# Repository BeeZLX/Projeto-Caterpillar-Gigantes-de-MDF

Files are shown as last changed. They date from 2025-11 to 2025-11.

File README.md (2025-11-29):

Programação de HardWare 2025

Grupo Caterpillar:

Vinicius Regis
Leticia Ribeiro
Caio Rodrigues

O projeto Gigantes de MDF envolve a criação integral de um robô móvel construído em MDF, incluindo todo o sistema de locomoção formado por motores DC acionados por PWM, um mecanismo de disparo a laser utilizando um diodo emissor de luz vermelho e um módulo de detecção baseado em LDR acoplado a um difusor.

A proposta do trabalho é colocar em prática os conteúdos estudados na disciplina de Programação de Hardware, operando diretamente com o microcontrolador ATmega328p, buscando apenas pelos componentes essenciais para o funcionamento básico do sistema.

Regras do Edital:
Dimensões máximas de 200 × 200 × 200 mm • Sistema com 2 a 4 rodas, capaz de realizar movimentação no próprio eixo • “Arma” laser posicionada no centro do robô, a 100 mm de altura • Receptor de luz instalado ao lado direito da arma, com difusor de 20 mm • Estrutura baseada em MDF, com cortes e montagem conforme projeto disponibilizado

O gigante de MDF deve cumprir as seguintes especificações:
 Utilizar o Microcontrolador ATmega328P, ter Controle dos motores via PWM, Laser temporizado por Timer, Receptor de luz (LDR) com rotina de interrupção, após cada acerto é obrigatorio ter um delay, utilização de leds para a simulação da "vida" do robõ, Rotina de giro automático de 180°, Reset de vidas via interrupção externa e ter o Código completamente documentado em Doxygen

Todo o conjunto — circuito eletrônico, firmware e documentação — foi idealizado, desenvolvido e implementado pela equipe.

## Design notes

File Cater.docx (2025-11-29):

Catepillar

Vinicius de Moraes Regis - RA: 230610

Leticia Ribeiro - RA: 233423

Caio Rodrigues - RA: 228282

# 1.Introdução do Projeto

O projeto gigantes de MDF desenvolvido para a matéria de Programação de Hardware, consiste em um robô que compõe de componentes eletrônicos como laser, Motor Dc e um LDR como sistema de recepção de luz.

Operando com o microcontrolado ATMEGA328P, temos o objetivo de aplicar os conhecimentos adquiridos nas aulas como TIMERS, PWM, UART, CTC e outros.

Sendo todas as etapas testadas e por fim, realizadas pelos integrantes do grupo, sendo elas circuito, estrutura, Software e documentação.

2. Composição da estrutura do Projeto

O robô realizado pelos alunos atendem as medidas (Dimensões) maximas de: 160 x 168.5 x 160mm, inteiramente feito de MDF (3mm) com ajuda do laboratório INOVFABLAB da UNIVERSIDADE SANTA CECÍLIA, contém com um sistema de movimentação de 2 (duas rodas) ligadas à 2 (dois) motores DC 3-6V,

1 (um) Circuito integrado de motor L293D, 1 (um) componente eletrônico (sensor de luz) LDR (20mm), 1 (um) laser vermelho de 300mW de Potência, 6 (seis) leds, sendo eles 3 para a vida do “GIGANTE DE MDF” e mais 3 como componente estético, 1 (um) Módulo Bluetooth HC-05 para a comunicação entre o robô, 2 (dois) Servo Motor como arma e o usuário e 2 (dois) microcontroladores ATMEGA328P.

Robô realizado atraves do Software: Fusion 360

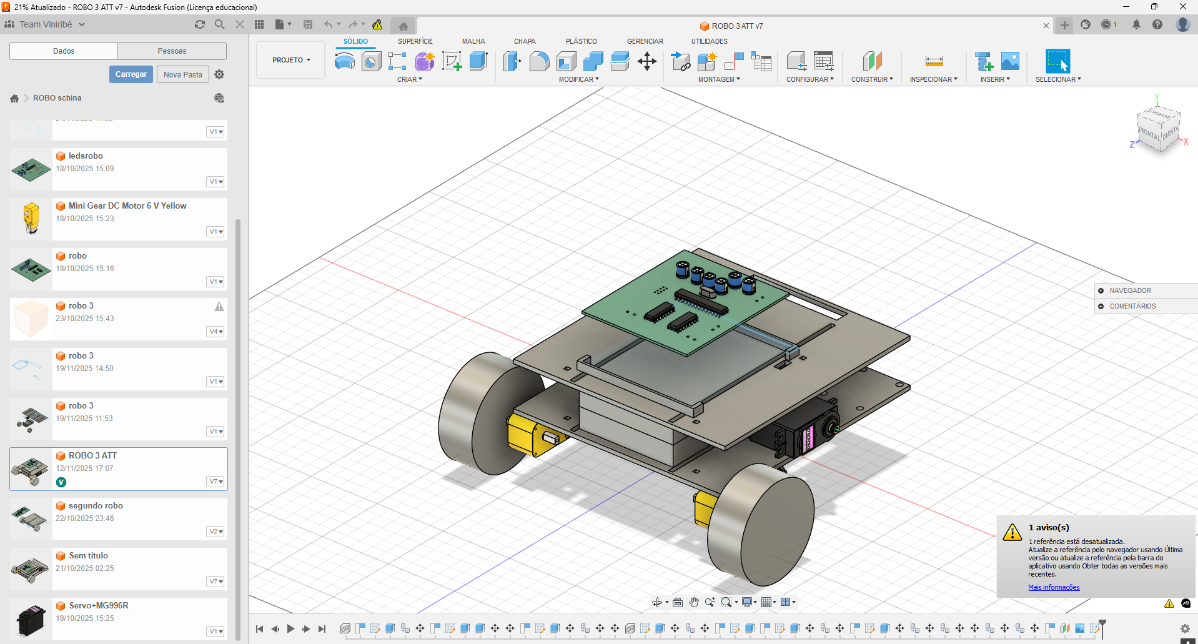
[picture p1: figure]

Circuitos realizados através do Software: KICAD

Circuito principal “Coração” do Gigante de MDF

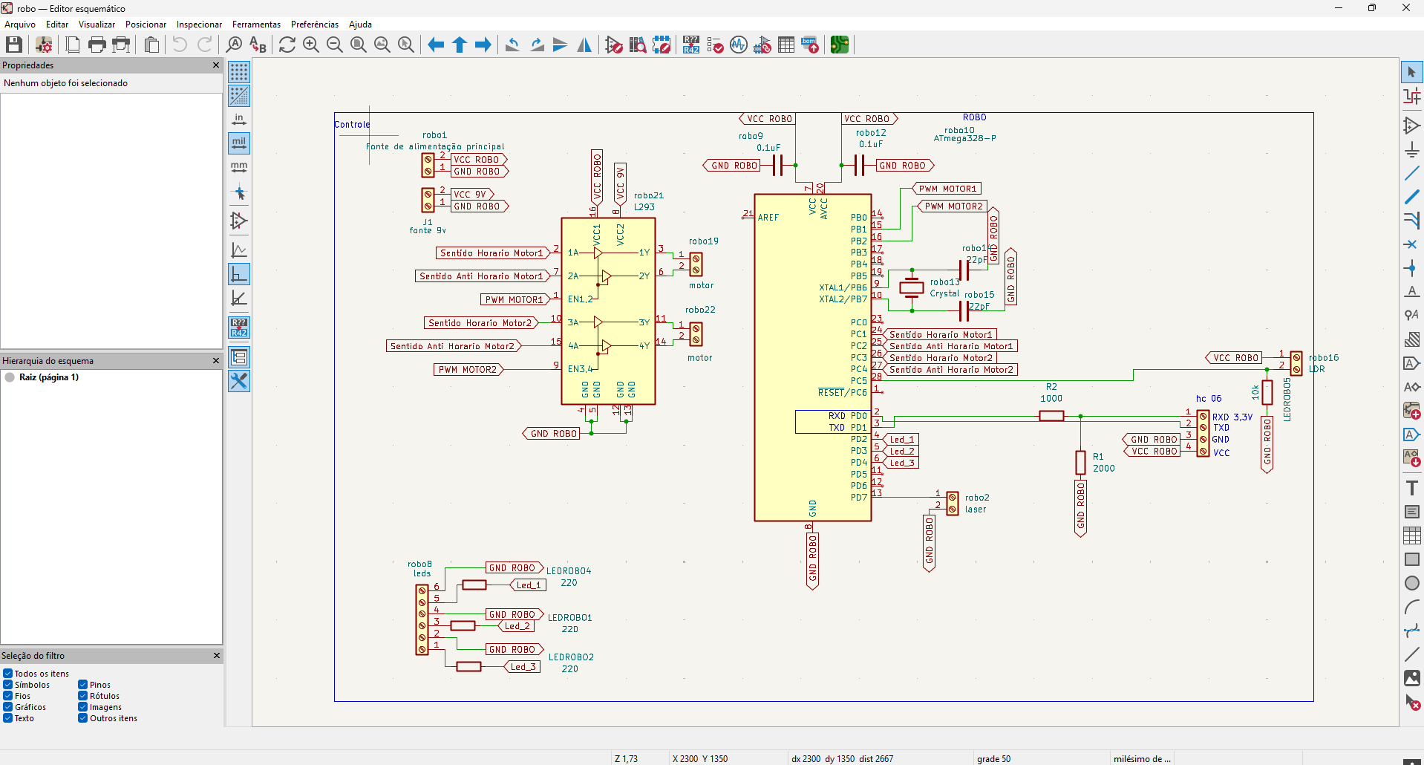
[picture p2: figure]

Circuito para as armas (Servos Motores)

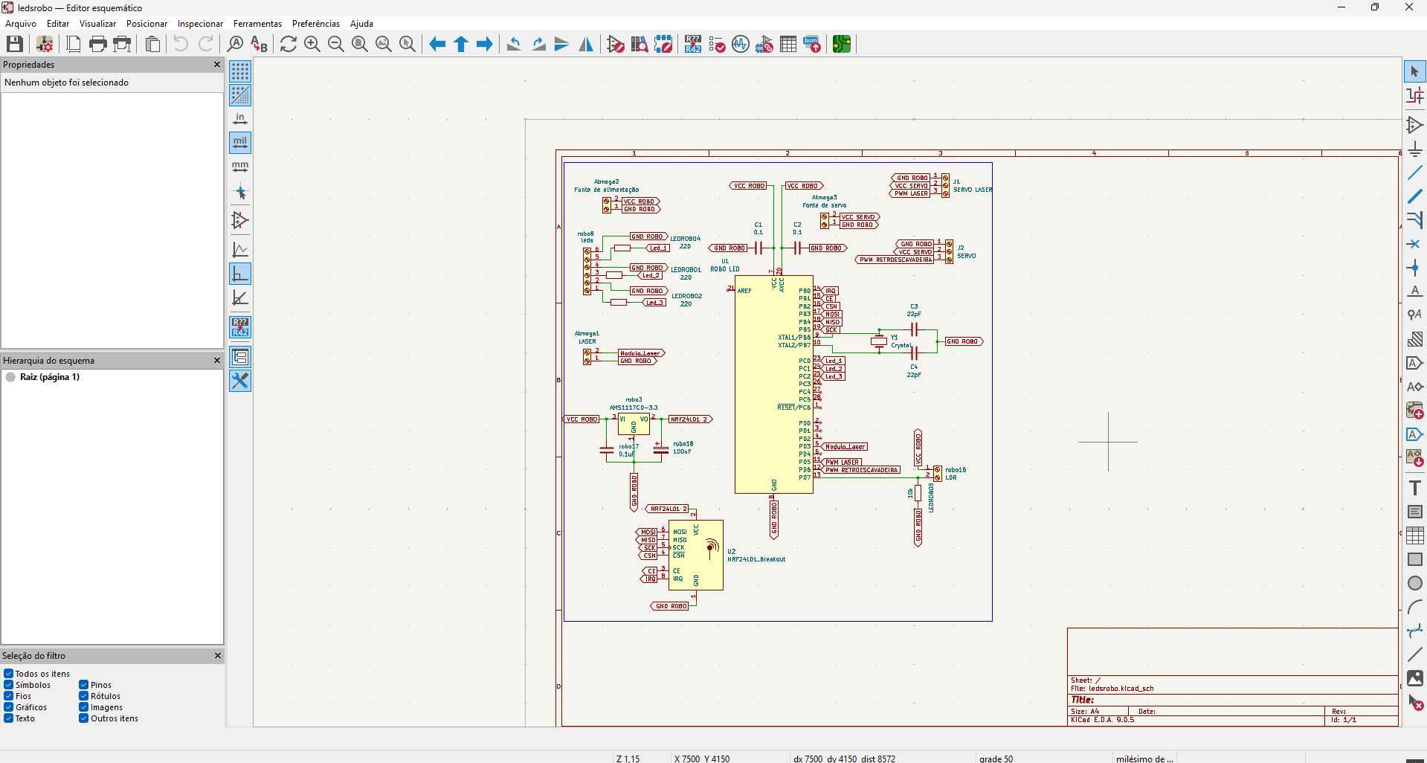
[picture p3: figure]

# 4.Simulação e Firmware

Antes da confecção das placas de Circuito, os alunos realizaram testes no simulados “Simulide”, fazendo com que toda a lógica por trás da construção do robô pudesse ser validada, reduzindo os riscos de falha e aumentando o sucesso do objetivo.

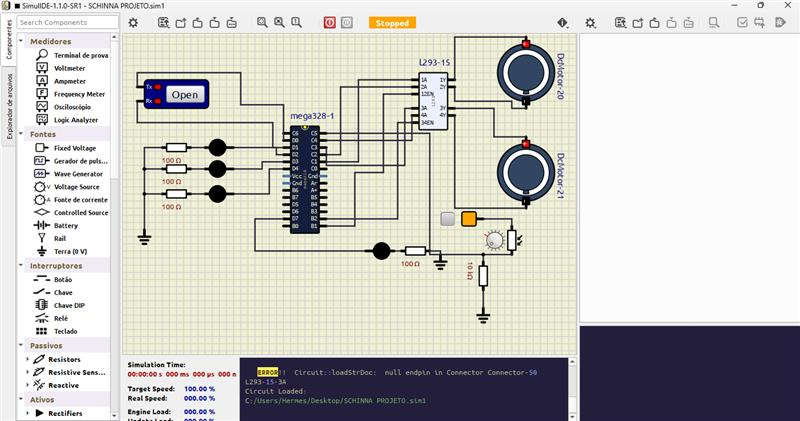
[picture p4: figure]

Após a criação e montagem da placa de circuito, os alunos realizaram a parte de firmware na linguagem C, utilizando todos os ensinamentos dado em aula em relação à TIMERS e PWM das aulas de Programações de Hardware

Para o desenvolvimento do projeto, foi utilizado os seguintes aplicativos:

Simulide: Aplicativo para a simulação de circuitos eletrônicos .

Fusion 360: Aplicativo utilizado para a medição e criação das estruturas do robô.

KICAD: Aplicativo para a criação das placas de circuitos.

Microchip Studio: Ambiente de programação para realizar os testes no simulide.

Arduino IDE: plataforma Arduino utilizado para a transferência de dados do programador para o microcontrolador ATMEGA328P.

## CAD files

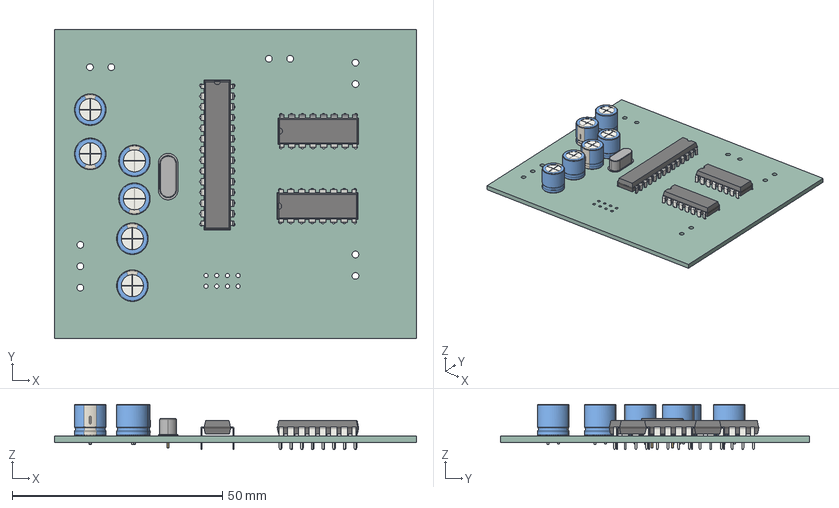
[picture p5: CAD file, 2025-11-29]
robo.step
86.0 x 73.5 x 10.8 mm
DIP-16_W7.62mm x 2
CP_Radial_D7.5mm_P2.50mm x 6
DIP-28_W7.62mm
Crystal_HC49-4H_Vertical
robo_PCB

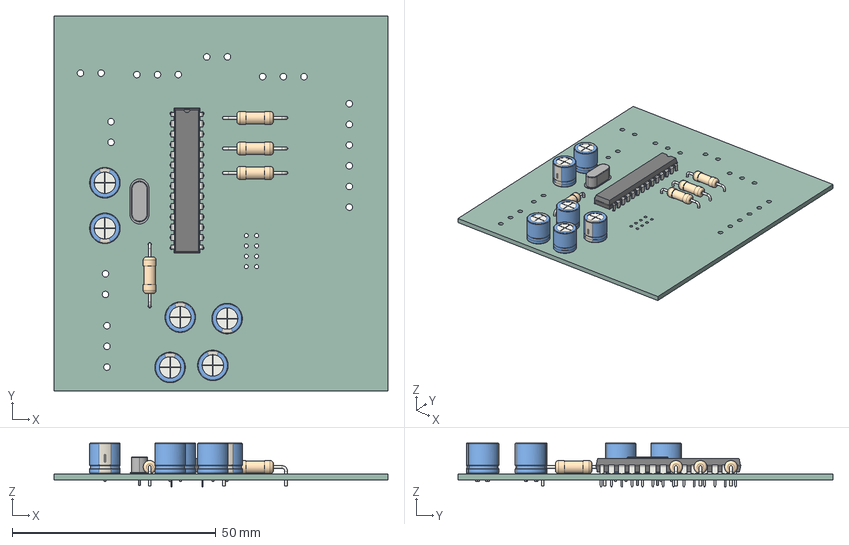
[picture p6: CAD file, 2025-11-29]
ledsrobo.step
82.0 x 92.0 x 10.8 mm
CP_Radial_D7.5mm_P2.50mm x 6
R_Axial_DIN0309_L9.0mm_D3.2mm_P15.24mm_Horizontal x 4
DIP-28_W7.62mm
Crystal_HC49-4H_Vertical
ledsrobo_PCB

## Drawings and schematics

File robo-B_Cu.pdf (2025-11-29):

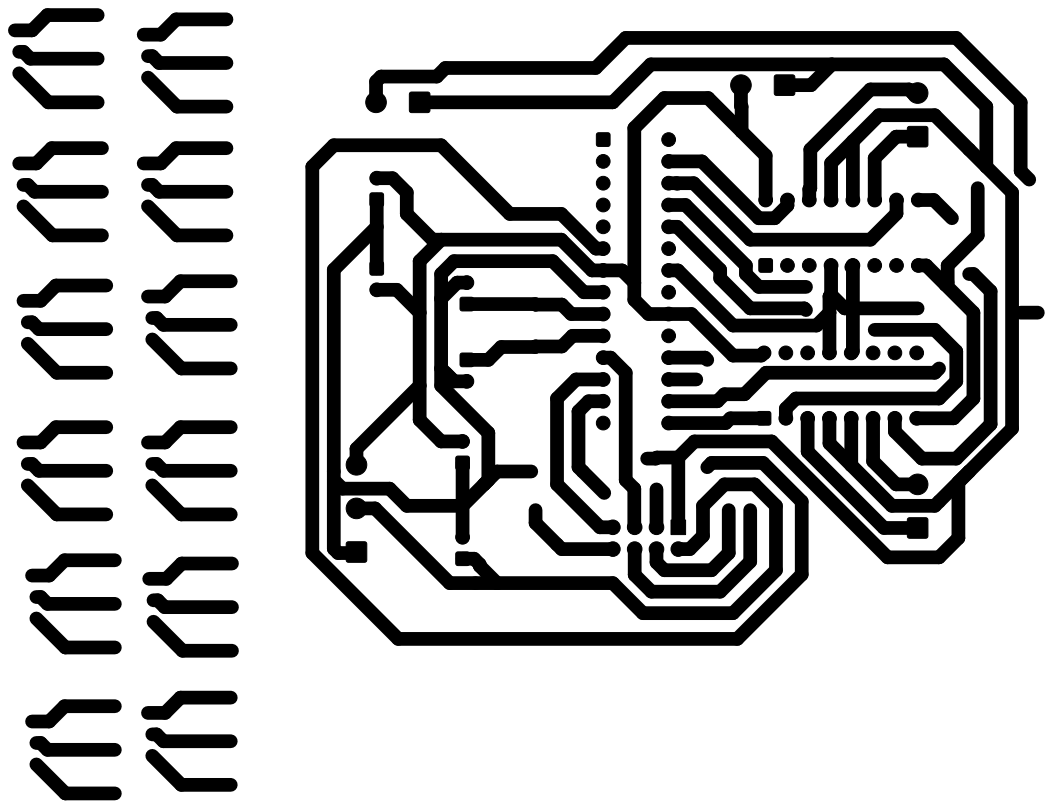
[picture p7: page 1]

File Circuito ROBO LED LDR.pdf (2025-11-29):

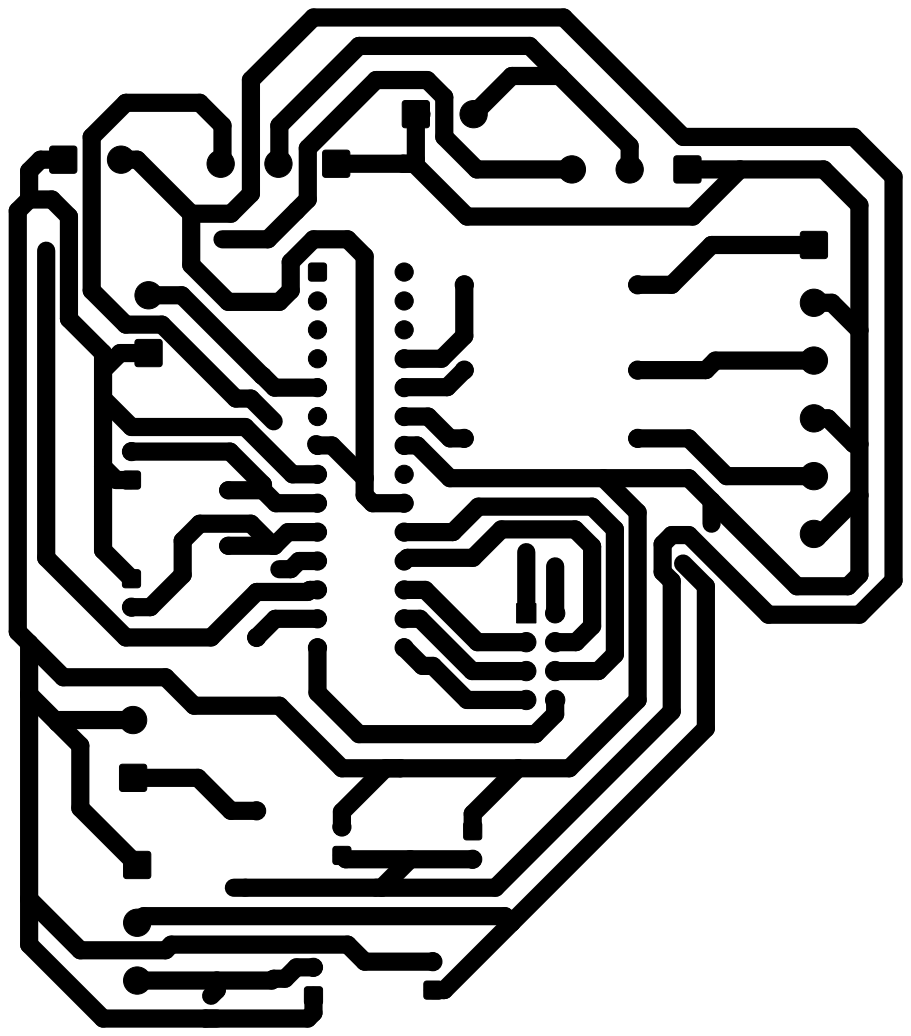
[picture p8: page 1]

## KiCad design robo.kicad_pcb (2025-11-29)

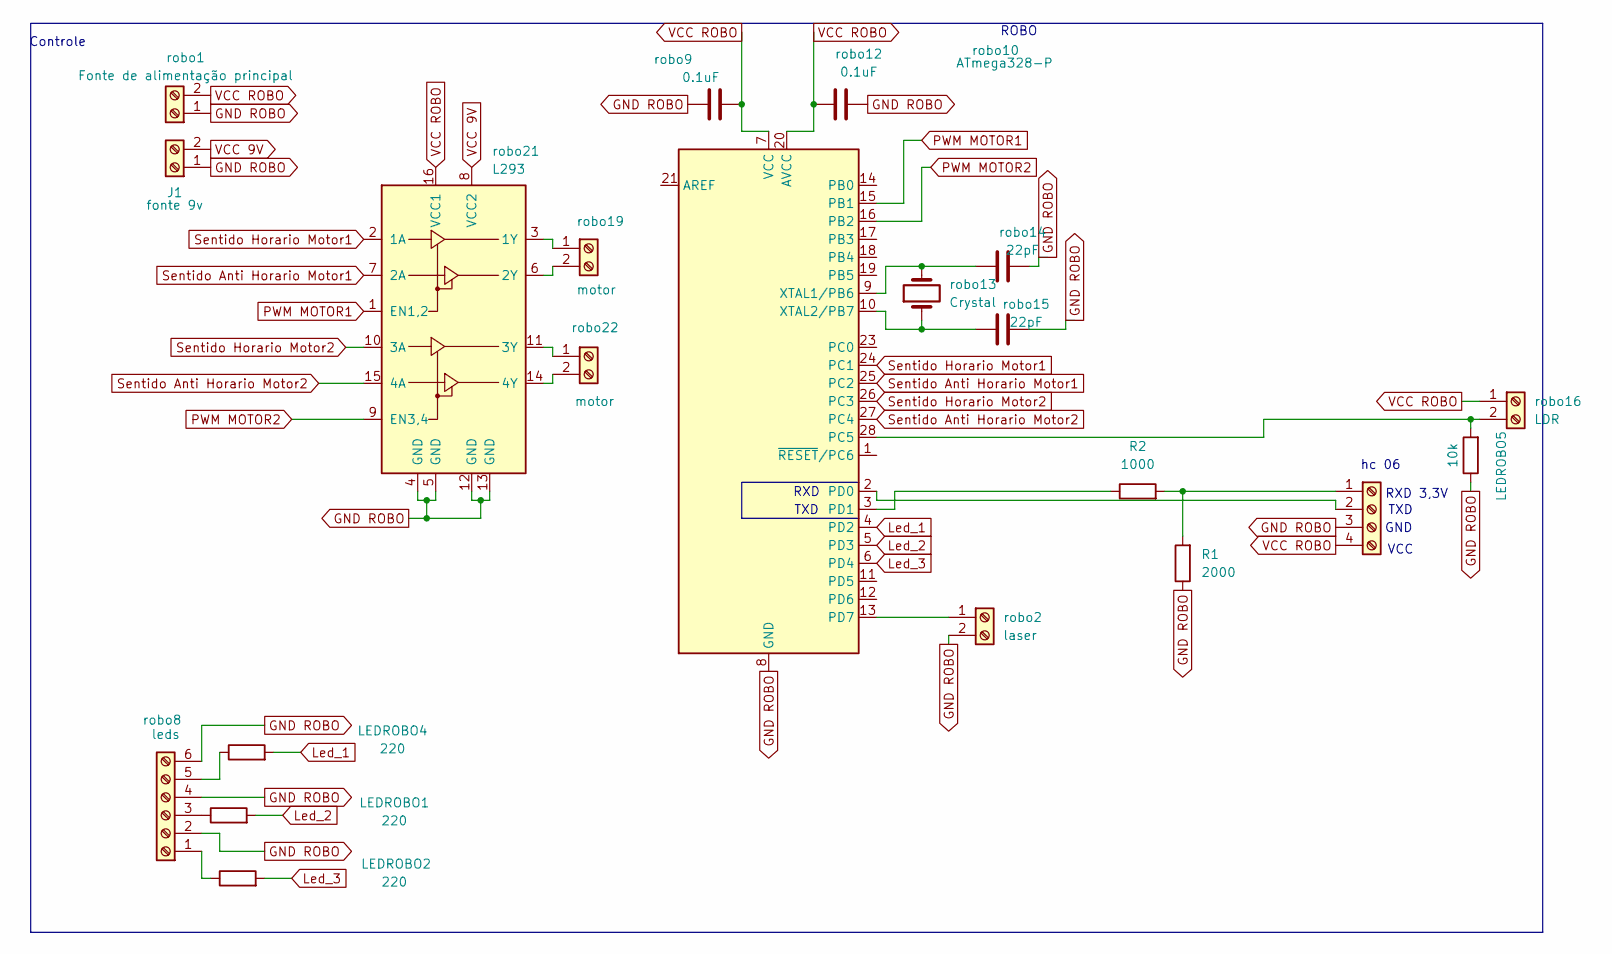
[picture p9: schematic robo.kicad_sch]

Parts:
J1: fonte 9v; TerminalBlock_CUI_TB007-508-02_1x02_P5.08mm_Horizontal
J3: hc06; TerminalBlock_CUI_TB007-508-04_1x04_P5.08mm_Horizontal
LEDROBO1, LEDROBO2, LEDROBO4: 220; R_Axial_DIN0309_L9.0mm_D3.2mm_P15.24mm_Horizontal
LEDROBO5: 10k; R_Axial_DIN0309_L9.0mm_D3.2mm_P15.24mm_Horizontal
R1: 2000; R_Axial_DIN0309_L9.0mm_D3.2mm_P15.24mm_Horizontal
R2: 1000; R_Axial_DIN0309_L9.0mm_D3.2mm_P15.24mm_Horizontal
robo1: Fonte de alimentação principal; TerminalBlock_CUI_TB007-508-02_1x02_P5.08mm_Horizontal
robo2: laser; TerminalBlock_CUI_TB007-508-02_1x02_P5.08mm_Horizontal
robo8: leds; TerminalBlock_CUI_TB007-508-06_1x06_P5.08mm_Horizontal
robo9, robo12: 0.1uF; CP_Radial_D7.5mm_P2.50mm
robo10: ATmega328-P; DIP-28_W7.62mm
robo13: Crystal; Crystal_HC49-4H_Vertical
robo14, robo15: 22pF; CP_Radial_D7.5mm_P2.50mm
robo16: LDR; TerminalBlock_CUI_TB007-508-02_1x02_P5.08mm_Horizontal
robo19, robo22: motor; TerminalBlock_CUI_TB007-508-02_1x02_P5.08mm_Horizontal
robo21: L293; DIP-16_W7.62mm

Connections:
GND ROBO: J1.1, J3.3, LEDROBO5.1, R1.1, robo1.1, robo2.2, robo8.2, robo8.4, robo8.6, robo9.1, robo10.8 (GND), robo10.22 (GND), robo12.1, robo14.2, robo15.2, robo21.4 (GND), robo21.5 (GND), robo21.12 (GND), robo21.13 (GND)
Led_1: LEDROBO4.2, robo10.4 (PD2)
Led_2: LEDROBO1.2, robo10.5 (PD3)
Led_3: LEDROBO2.2, robo10.6 (PD4)
unnamed: J3.1, R1.2, R2.2
unnamed: J3.2, robo10.2 (PD0)
unnamed: LEDROBO2.1, robo8.1
unnamed: LEDROBO1.1, robo8.3
unnamed: LEDROBO4.1, robo8.5
unnamed: LEDROBO5.2, robo10.28 (PC5), robo16.2
unnamed: R2.1, robo10.3 (PD1)
unnamed: robo2.1, robo10.13 (PD7)
unnamed: robo10.9 (XTAL1/PB6), robo13.2, robo14.1
unnamed: robo10.10 (XTAL2/PB7), robo13.1, robo15.1
unnamed: robo19.1, robo21.3 (1Y)
unnamed: robo19.2, robo21.6 (2Y)
unnamed: robo21.11 (3Y), robo22.1
unnamed: robo21.14 (4Y), robo22.2
PWM MOTOR1: robo10.15 (PB1), robo21.1 (EN1,2)
PWM MOTOR2: robo10.16 (PB2), robo21.9 (EN3,4)
Sentido Anti Horario Motor1: robo10.25 (PC2), robo21.7 (2A)
Sentido Anti Horario Motor2: robo10.27 (PC4), robo21.15 (4A)
Sentido Horario Motor1: robo10.24 (PC1), robo21.2 (1A)
Sentido Horario Motor2: robo10.26 (PC3), robo21.10 (3A)
VCC 9V: J1.2, robo21.8 (VCC2)
VCC ROBO: J3.4, robo1.2, robo9.2, robo10.7 (VCC), robo10.20 (AVCC), robo12.2, robo16.1, robo21.16 (VCC1)

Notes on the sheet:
ROBO
RXD 3,3V
GND
Controle
TXD
VCC
RXD
hc 06

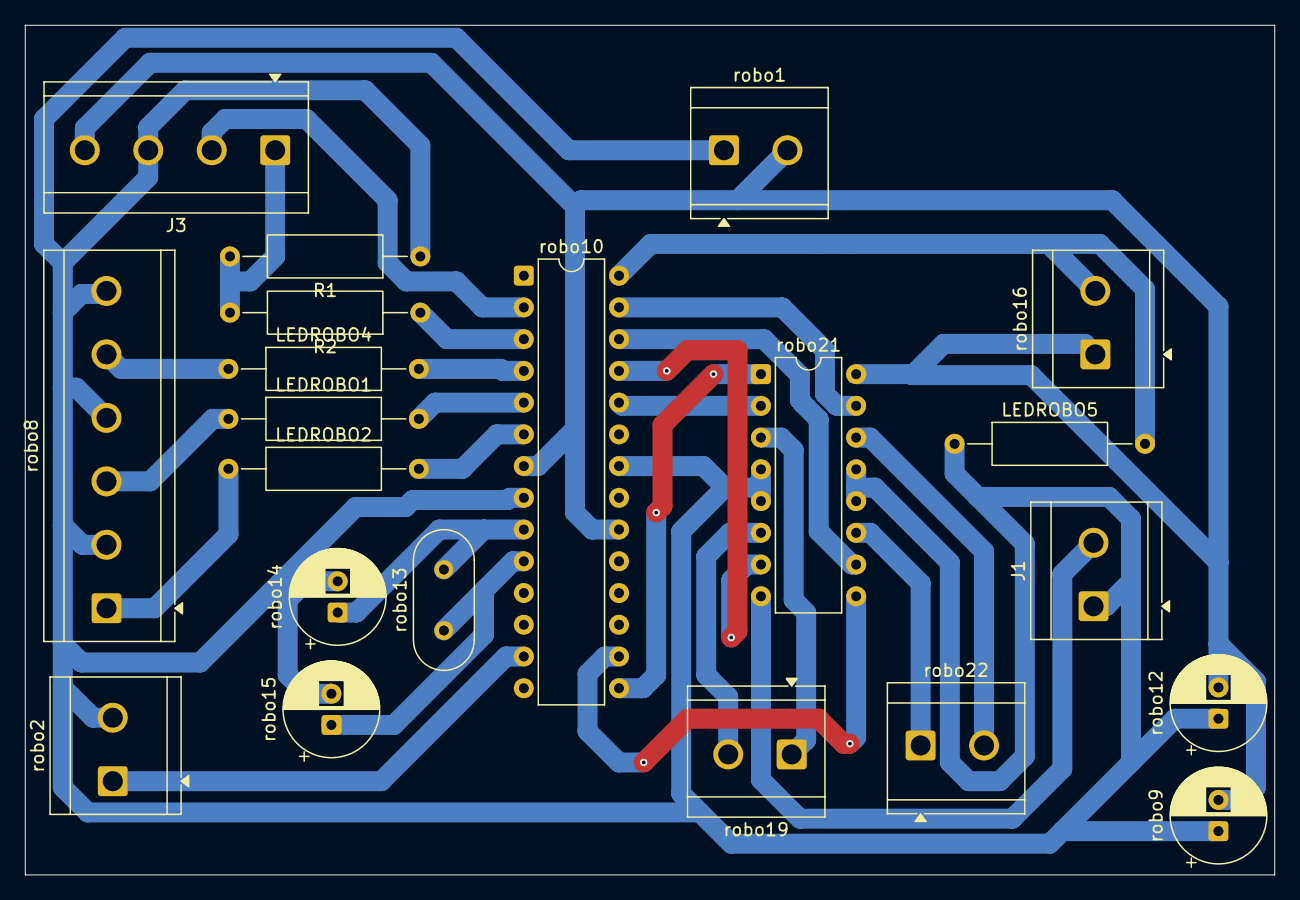
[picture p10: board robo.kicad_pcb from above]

Board: 2 copper layers, 100.0 x 68.0 mm, 21 parts (0 on the bottom side), 26 nets.

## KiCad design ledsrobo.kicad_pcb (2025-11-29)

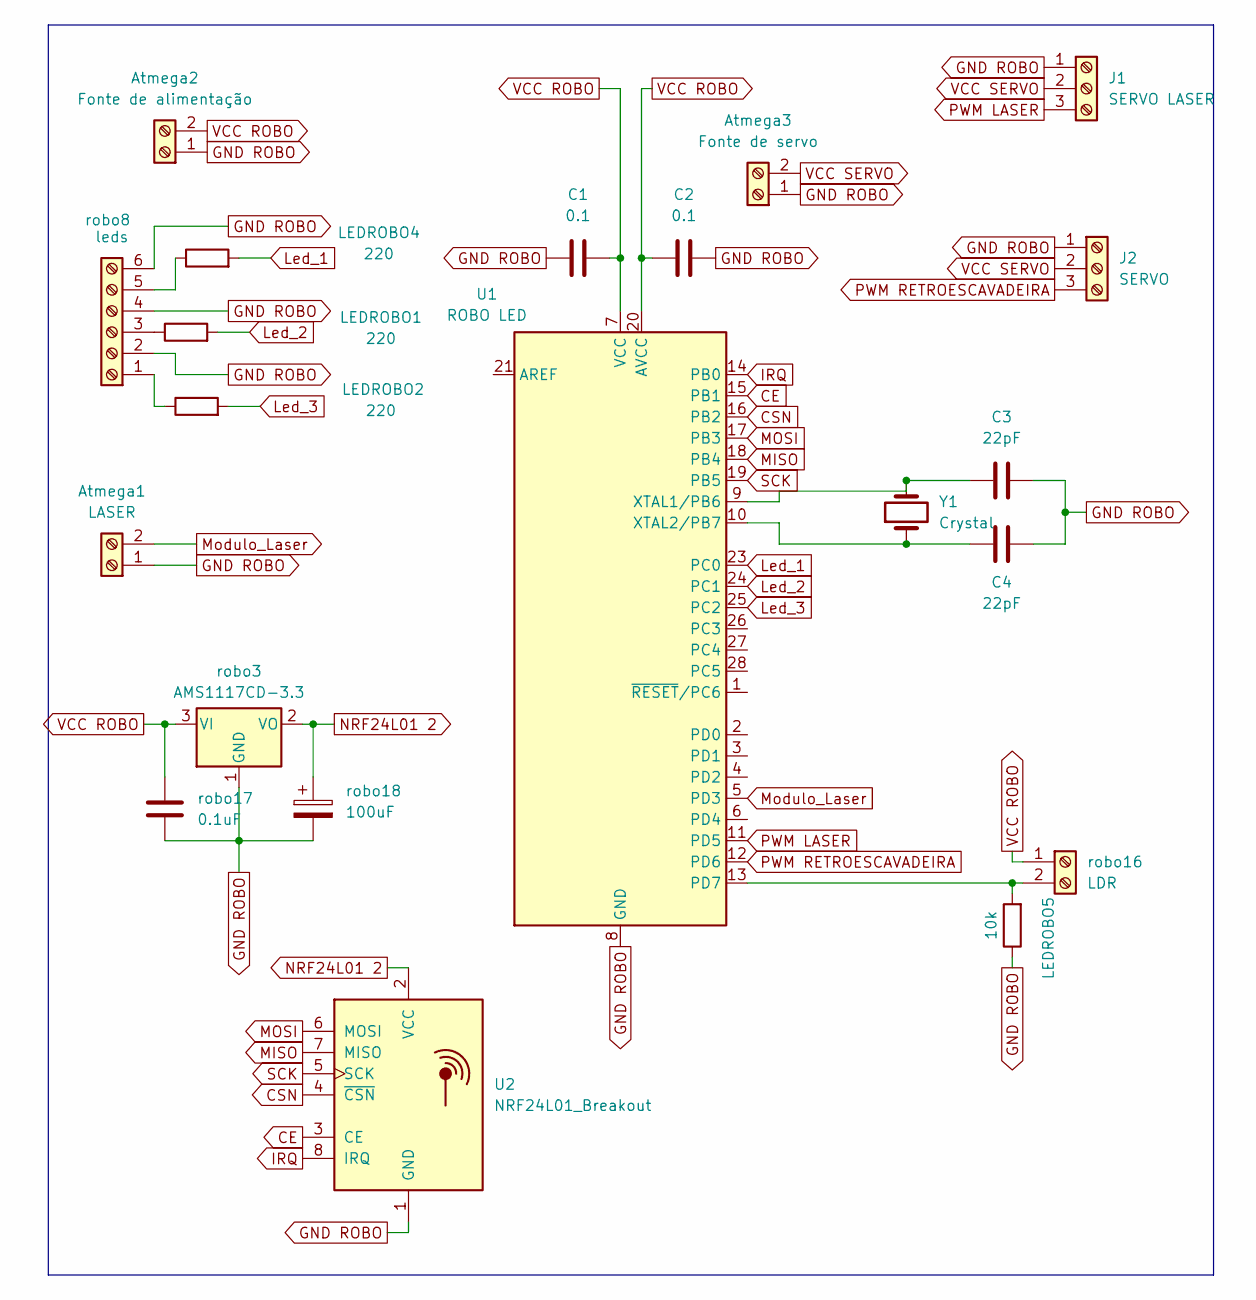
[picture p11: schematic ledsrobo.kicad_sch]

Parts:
Atmega1: LASER; TerminalBlock_CUI_TB007-508-02_1x02_P5.08mm_Horizontal
Atmega2: Fonte de alimentação; TerminalBlock_CUI_TB007-508-02_1x02_P5.08mm_Horizontal
Atmega3: Fonte de servo; TerminalBlock_CUI_TB007-508-02_1x02_P5.08mm_Horizontal
C1, C2: 0.1; CP_Radial_D7.5mm_P2.50mm
C3, C4: 22pF; CP_Radial_D7.5mm_P2.50mm
J1: SERVO LASER; TerminalBlock_CUI_TB007-508-03_1x03_P5.08mm_Horizontal
J2: SERVO; TerminalBlock_CUI_TB007-508-03_1x03_P5.08mm_Horizontal
LEDROBO1, LEDROBO2, LEDROBO4: 220; R_Axial_DIN0309_L9.0mm_D3.2mm_P15.24mm_Horizontal
LEDROBO5: 10k; R_Axial_DIN0309_L9.0mm_D3.2mm_P15.24mm_Horizontal
U1: ROBO LED; DIP-28_W7.62mm
U2: NRF24L01_Breakout; nRF24L01_Breakout
Y1: Crystal; Crystal_HC49-4H_Vertical
robo3: AMS1117CD-3.3; TerminalBlock_CUI_TB007-508-03_1x03_P5.08mm_Horizontal
robo8: leds; TerminalBlock_CUI_TB007-508-06_1x06_P5.08mm_Horizontal
robo16: LDR; TerminalBlock_CUI_TB007-508-02_1x02_P5.08mm_Horizontal
robo17: 0.1uF; CP_Radial_D7.5mm_P2.50mm
robo18: 100uF; CP_Radial_D7.5mm_P2.50mm

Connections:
CE: U1.15 (PB1), U2.3 (CE)
CSN: U1.16 (PB2), U2.4 (~CSN)
GND ROBO: Atmega1.1, Atmega2.1, Atmega3.1, C1.2, C2.1, C3.1, C4.1, J1.1, J2.1, LEDROBO5.1, U1.8 (GND), U1.22 (GND), U2.1 (GND), robo3.1 (GND), robo8.2, robo8.4, robo8.6, robo17.1, robo18.2
IRQ: U1.14 (PB0), U2.8 (IRQ)
Led_1: LEDROBO4.2, U1.23 (PC0)
Led_2: LEDROBO1.2, U1.24 (PC1)
Led_3: LEDROBO2.2, U1.25 (PC2)
MISO: U1.18 (PB4), U2.7 (MISO)
MOSI: U1.17 (PB3), U2.6 (MOSI)
Modulo_Laser: Atmega1.2, U1.5 (PD3)
NRF24L01 2: U2.2 (VCC), robo3.2 (VO), robo18.1
unnamed 11: LEDROBO5.2, U1.13 (PD7), robo16.2; also elsewhere on the board
unnamed: C3.2, U1.9 (XTAL1/PB6), Y1.2
unnamed: C4.2, U1.10 (XTAL2/PB7), Y1.1
unnamed: LEDROBO2.1, robo8.1
unnamed: LEDROBO1.1, robo8.3
unnamed: LEDROBO4.1, robo8.5
PWM LASER: J1.3, U1.11 (PD5)
PWM RETROESCAVADEIRA: J2.3, U1.12 (PD6)
SCK: U1.19 (PB5), U2.5 (SCK)
VCC ROBO: Atmega2.2, C1.1, C2.2, U1.7 (VCC), U1.20 (AVCC), robo3.3 (VI), robo16.1, robo17.2
VCC SERVO: Atmega3.2, J1.2, J2.2

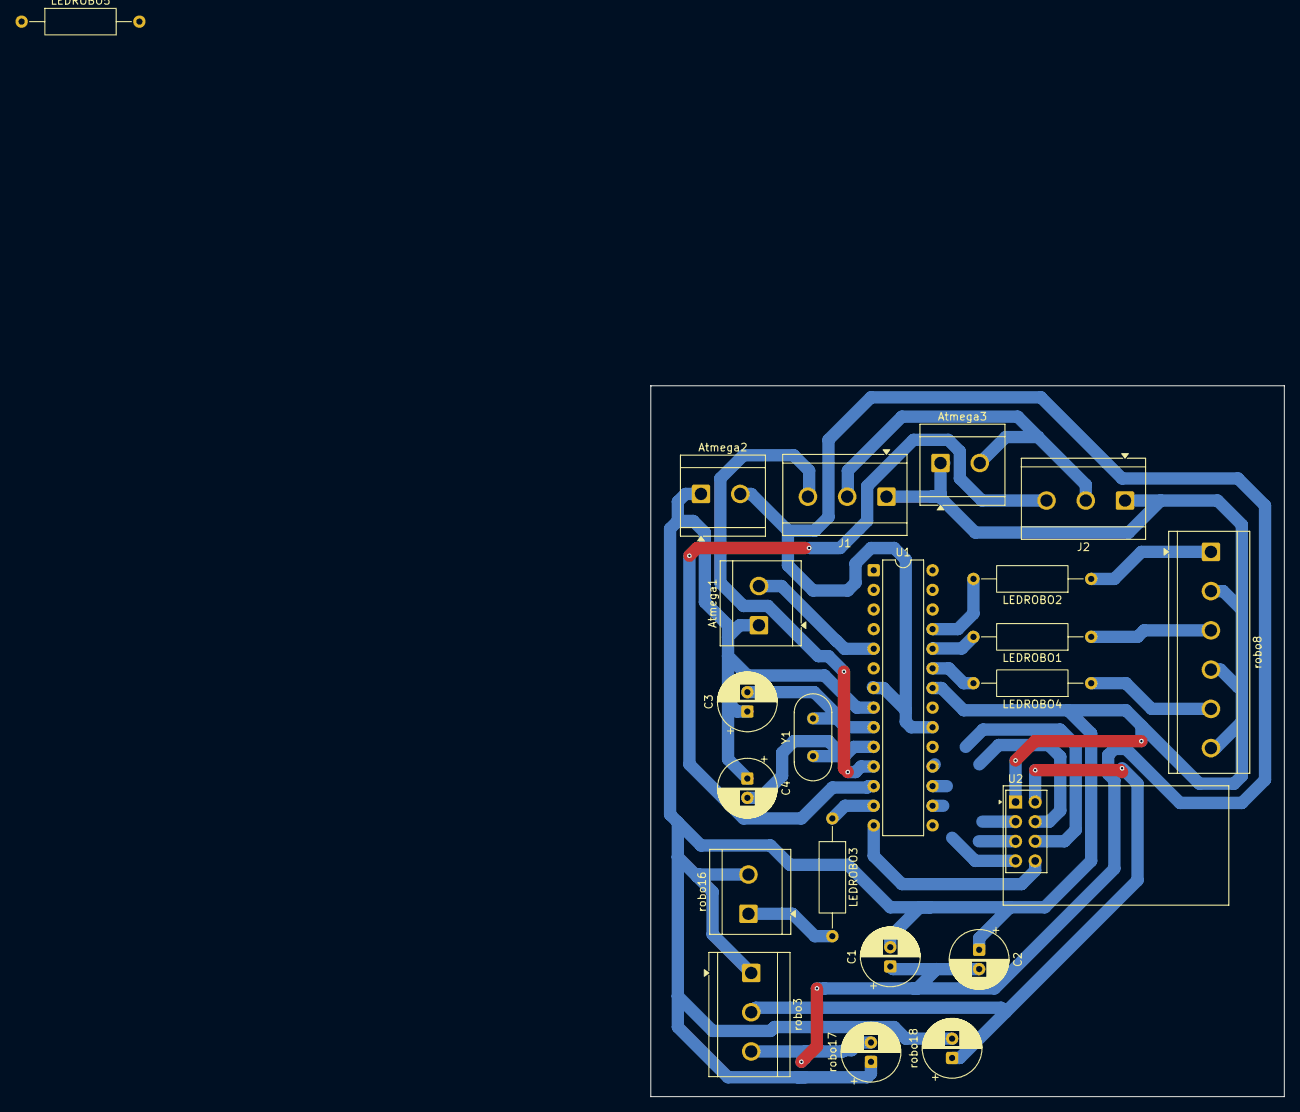
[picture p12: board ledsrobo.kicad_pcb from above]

Board: 2 copper layers, 82.0 x 92.0 mm, 22 parts (0 on the bottom side), 22 nets.

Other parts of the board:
LEDROBO3: 10k; R_Axial_DIN0309_L9.0mm_D3.2mm_P15.24mm_Horizontal

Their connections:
unnamed 11: LEDROBO3.1; also elsewhere on the board

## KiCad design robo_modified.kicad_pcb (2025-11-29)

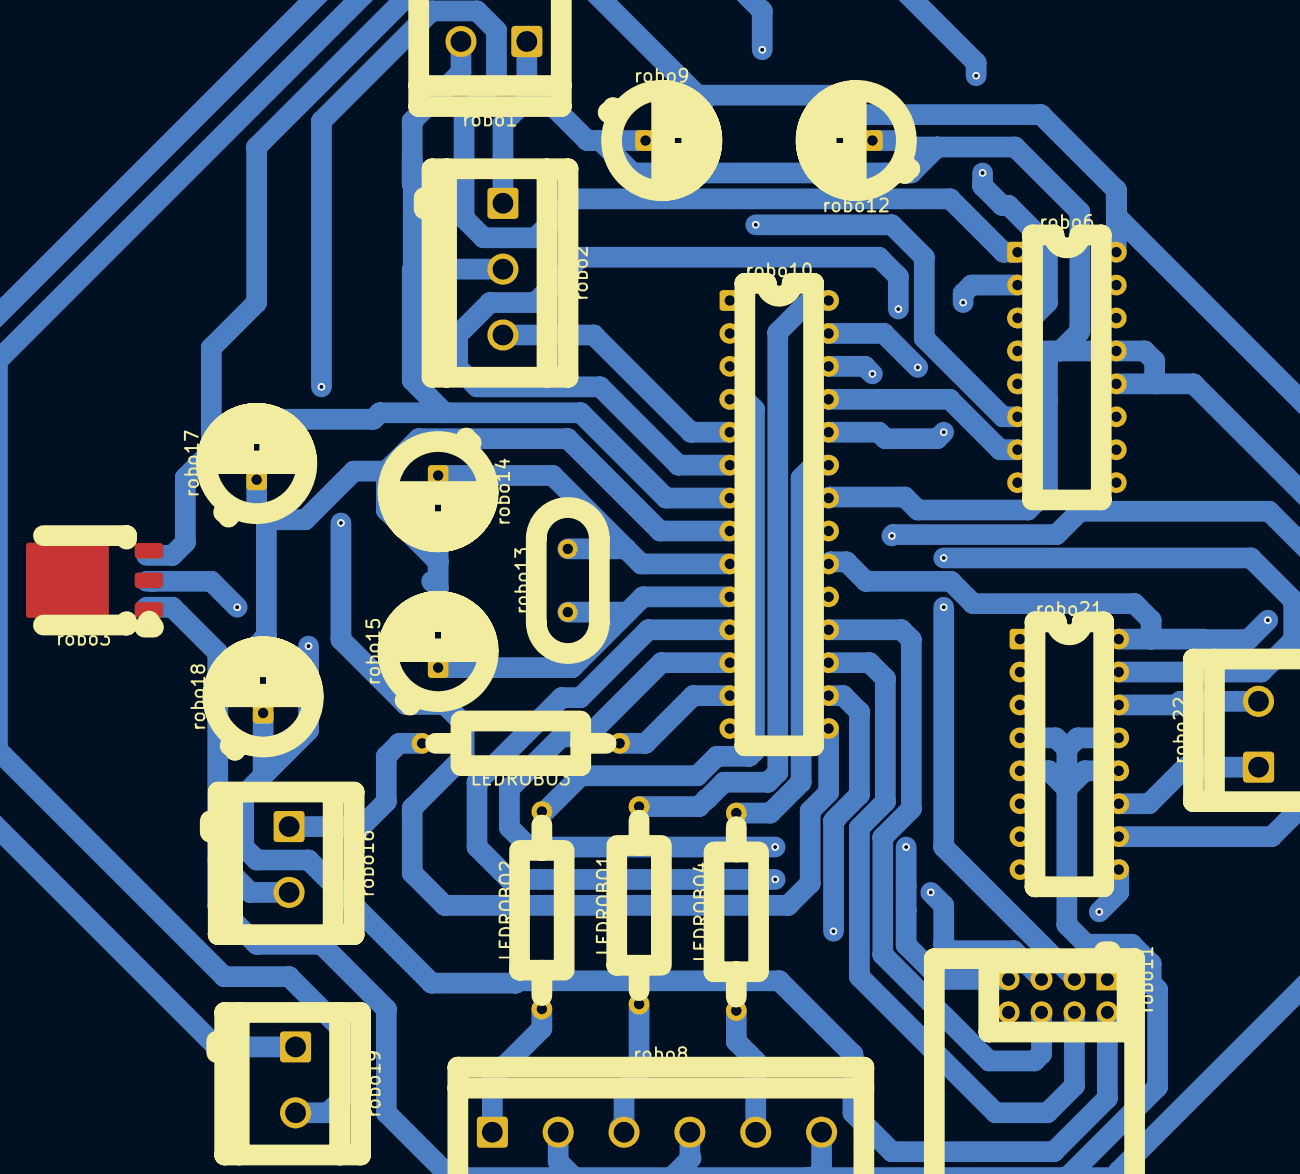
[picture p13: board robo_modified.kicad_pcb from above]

Board: 2 copper layers, 22 parts (0 on the bottom side), 29 nets.

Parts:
LEDROBO1, LEDROBO2, LEDROBO4: 220; R_Axial_DIN0309_L9.0mm_D3.2mm_P15.24mm_Horizontal
LEDROBO3: 10k; R_Axial_DIN0309_L9.0mm_D3.2mm_P15.24mm_Horizontal
robo1: Fonte de alimentação principal; TerminalBlock_CUI_TB007-508-02_1x02_P5.08mm_Horizontal
robo2: Laser; TerminalBlock_CUI_TB007-508-03_1x03_P5.08mm_Horizontal
robo3: AMS1117CD-3.3; TO-252-3_TabPin2
robo6, robo21: L293; DIP-16_W7.62mm
robo8: leds; TerminalBlock_CUI_TB007-508-06_1x06_P5.08mm_Horizontal
robo9, robo12, robo17: 0.1uF; CP_Radial_D7.5mm_P2.50mm
robo10: ATmega328-P; DIP-28_W7.62mm
robo11: NRF24L01_Breakout; nRF24L01_Breakout
robo13: Crystal; Crystal_HC49-4H_Vertical
robo14, robo15: C; CP_Radial_D7.5mm_P2.50mm
robo16: LDR; TerminalBlock_CUI_TB007-508-02_1x02_P5.08mm_Horizontal
robo18: 100uF; CP_Radial_D7.5mm_P2.50mm
robo19, robo22: motor; TerminalBlock_CUI_TB007-508-02_1x02_P5.08mm_Horizontal

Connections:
Digital NRF03 2: robo10.6 (PD4), robo11.3 (CE)
Digital NRF05 2: robo10.11 (PD5), robo11.5 (SCK)
Digital NRF07 2: robo10.12 (PD6), robo11.7 (MISO)
GND ROBO: robo1.1, robo2.1, robo3.1 (GND), robo6.4 (GND), robo6.5 (GND), robo6.12 (GND), robo6.13 (GND), robo8.2, robo8.4, robo8.6, robo9.1, robo10.8 (GND), robo10.22 (GND), robo11.1 (GND), robo12.1, robo14.2, robo15.2, robo16.2, robo17.1, robo18.2, robo21.4 (GND), robo21.5 (GND), robo21.12 (GND), robo21.13 (GND)
Led_1: LEDROBO4.2, robo10.23 (PC0)
Led_2: LEDROBO1.2, robo10.28 (PC5)
Led_3: LEDROBO2.2, robo10.4 (PD2)
Modulo_Laser: robo2.3, robo10.5 (PD3)
NRF24L01 2: robo3.2 (VO), robo11.2 (VCC), robo18.1
unnamed: LEDROBO2.1, robo8.1
unnamed: LEDROBO1.1, robo8.3
unnamed: LEDROBO4.1, robo8.5
unnamed: LEDROBO3.1, robo10.13 (PD7)
unnamed: robo10.9 (XTAL1/PB6), robo13.2, robo14.1
unnamed: robo10.10 (XTAL2/PB7), robo13.1, robo15.1
unnamed: LEDROBO3.2, robo16.1
unnamed: robo6.3 (1Y), robo19.1
unnamed: robo6.6 (2Y), robo19.2
unnamed: robo21.11 (3Y), robo22.1
unnamed: robo21.14 (4Y), robo22.2
PWM MOTOR1: robo6.1 (EN1,2), robo10.15 (PB1)
PWM MOTOR2: robo10.16 (PB2), robo21.9 (EN3,4)
PWM NRF04 2: robo10.17 (PB3), robo11.4 (~CSN)
PWM NRF06 2: robo10.18 (PB4), robo11.6 (MOSI)
Sentido Anti Horario Motor1: robo6.7 (2A), robo10.25 (PC2)
Sentido Anti Horario Motor2: robo10.27 (PC4), robo21.15 (4A)
Sentido Horario Motor1: robo6.2 (1A), robo10.24 (PC1)
Sentido Horario Motor2: robo10.26 (PC3), robo21.10 (3A)
VCC ROBO: robo1.2, robo2.2, robo3.3 (VI), robo6.16 (VCC1), robo9.2, robo10.7 (VCC), robo10.20 (AVCC), robo12.2, robo17.2, robo21.16 (VCC1)

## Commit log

2025-11-29 Placa 2 (Arma) (Servos Motor)
    [ledsrobo.kicad_pcb, ledsrobo.kicad_sch, ledsrobo.step]
2025-11-29 Placa 1 (Coração)
    [robo.kicad_pcb, robo.kicad_sch, robo.step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]
